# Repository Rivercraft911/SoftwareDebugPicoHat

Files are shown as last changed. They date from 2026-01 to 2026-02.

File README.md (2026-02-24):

# Software Debug Pico Hat

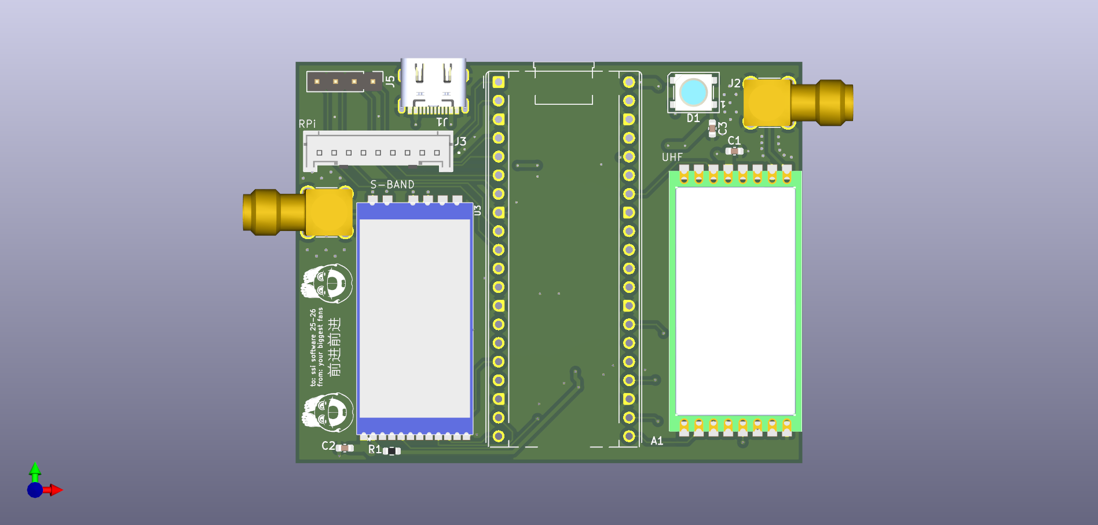
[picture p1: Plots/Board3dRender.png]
Board Render


A simple breakout board for the Raspberry Pi Pico, designed for S-Band and UHF LORA modules. It also includes exposed gpio pins for connection to other boards within the Samwise avionics stack.

[View Schematic PDF](Plots/SoftwareDebugPicoHat.pdf)

## Power

//type this up later frfr

## Pinout

This board connects to a Raspberry Pi Pico and provides the following pinouts:

### Raspberry Pi Communication
| Pin | Function | Pico Pin |
|-----|---|---|
| 0 | RPI_TX | GP0 |
| 1 | RPI_RX | GP1 |
| 2 | RPI_ENABLE | GP2 |
| 3 | RPI_RESET | GP3 |

### ACDS Communication
| Pin | Function | Pico Pin |
|-----|---|---|
| 4 | ACDS_TX | GP4 |
| 5 | ACDS_RX | GP5 |

### S-Band Module (LORA1280F27-TCXO)
| Pin | Function | Pico Pin |
|-----|---|---|
| 8 | SBAND_RST | GP8 |
| 9 | SBAND_BUSY | GP9 |
| 10  | SBAND_TXEN | GP10 |
| 11  | SBAND_RXEN | GP11 |
| 12  | SBAND_MISO | GP12 |
| 13  | SBAND_CS | GP13 |
| 14  | SBAND_SCK | GP14 |
| 15  | SBAND_MOSI | GP15 |
| 20  | SBAND_D1 | GP20 |

### UHF LORA Module (RFM98PW)
| Pin | Function | Pico Pin |
|-----|---|---|
| 16  | UHF_MISO | GP16 |
| 17  | UHF_CS | GP17 |
| 18  | UHF_SCK | GP18 |
| 19  | UHF_MOSI | GP19 |
| 20  | UHF_RST | GP21 |
| 28  | UHF_D0 | GP28 |

### Miscellaneous
| Pin | Function | Pico Pin |
|-----|---|---|
| 26  | NEOPIXEL | GP26 |
| 6 | MISC | GP6 |
| 7 | MISC | GP7 |

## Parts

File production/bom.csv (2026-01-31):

Designator | Footprint | Quantity | Value | LCSC Part #
A1 | RaspberryPi_Pico_Common_THT | 1 | RaspberryPi_Pico
C1, C2, C3 | 0603 | 3 | 0.1uF
D1 | LED_WS2812B_PLCC4_5.0x5.0mm_P3.2mm | 1 | 1655
J1 | Molex_35362-0950 | 1 | 35362-0950
J2, J4 | SMA_Amphenol_901-144_horizontal | 2 | Conn_Coaxial
J3 | USB_C_Receptacle_XKB_U262-161N-4BVC11 | 1 | USB_C_Receptacle_USB2.0_14P
J5 | PinHeader_1x04_P2.54mm_Vertical | 1 | Conn_01x04_Pin
R1 | 0603 | 1 | 10k
U1 | RFM98PW | 1 | RFM98PW
U3 | LORA128XF27 | 1 | LORA1280F27-TCXO

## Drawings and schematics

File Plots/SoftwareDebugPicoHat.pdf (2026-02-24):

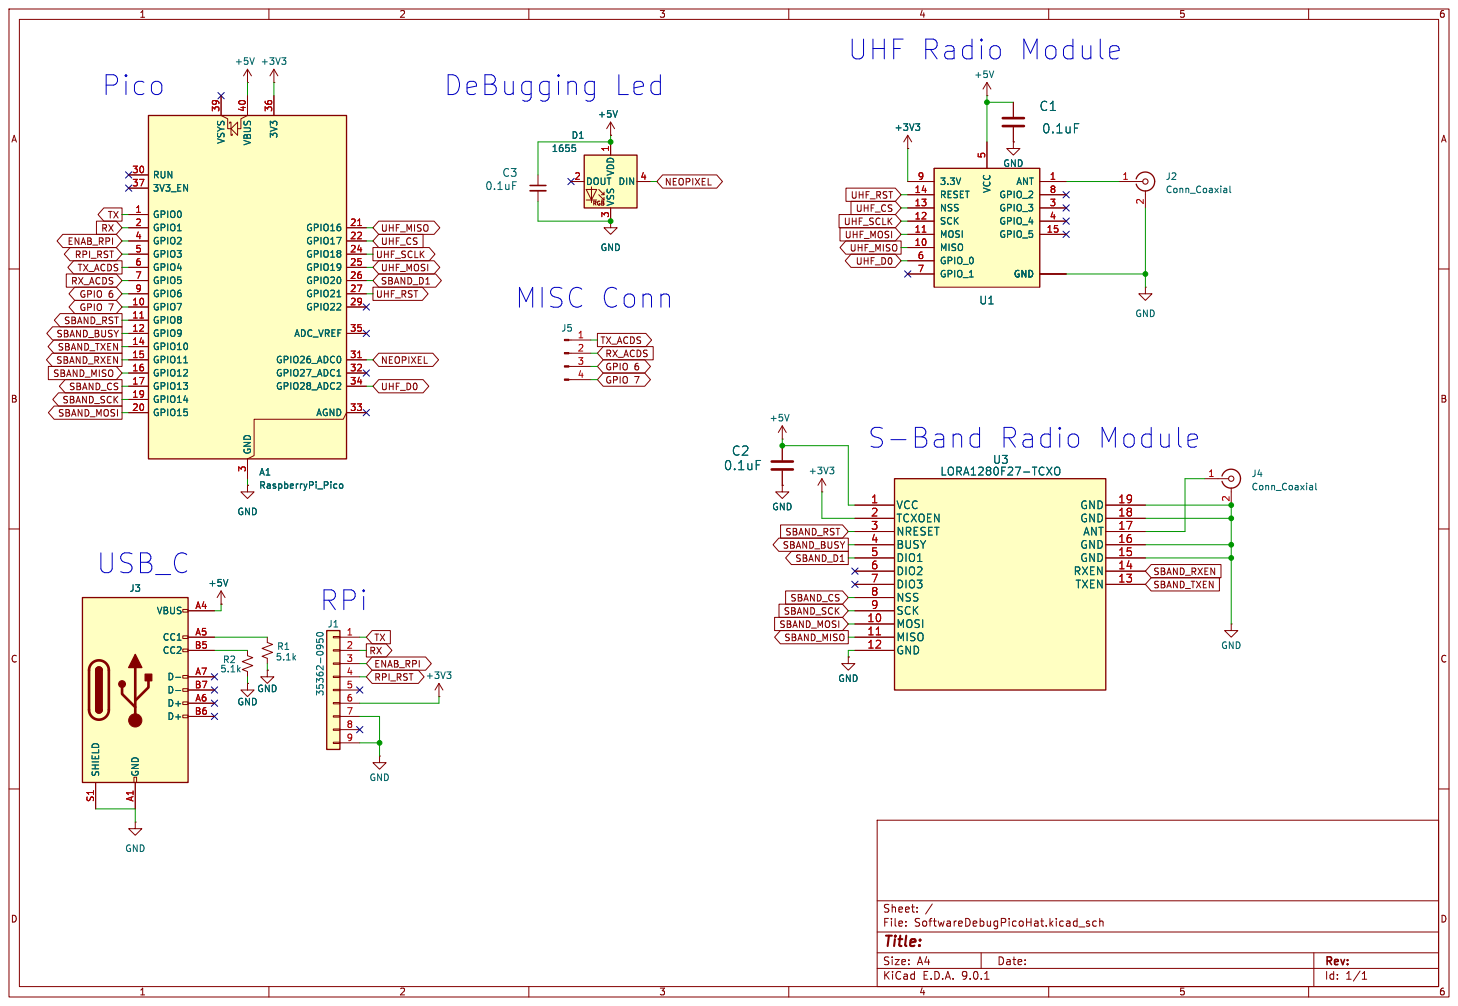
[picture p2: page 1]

Id: 1/1 Title: File: SoftwareDebugPicoHat.kicad_sch Sheet: / GND

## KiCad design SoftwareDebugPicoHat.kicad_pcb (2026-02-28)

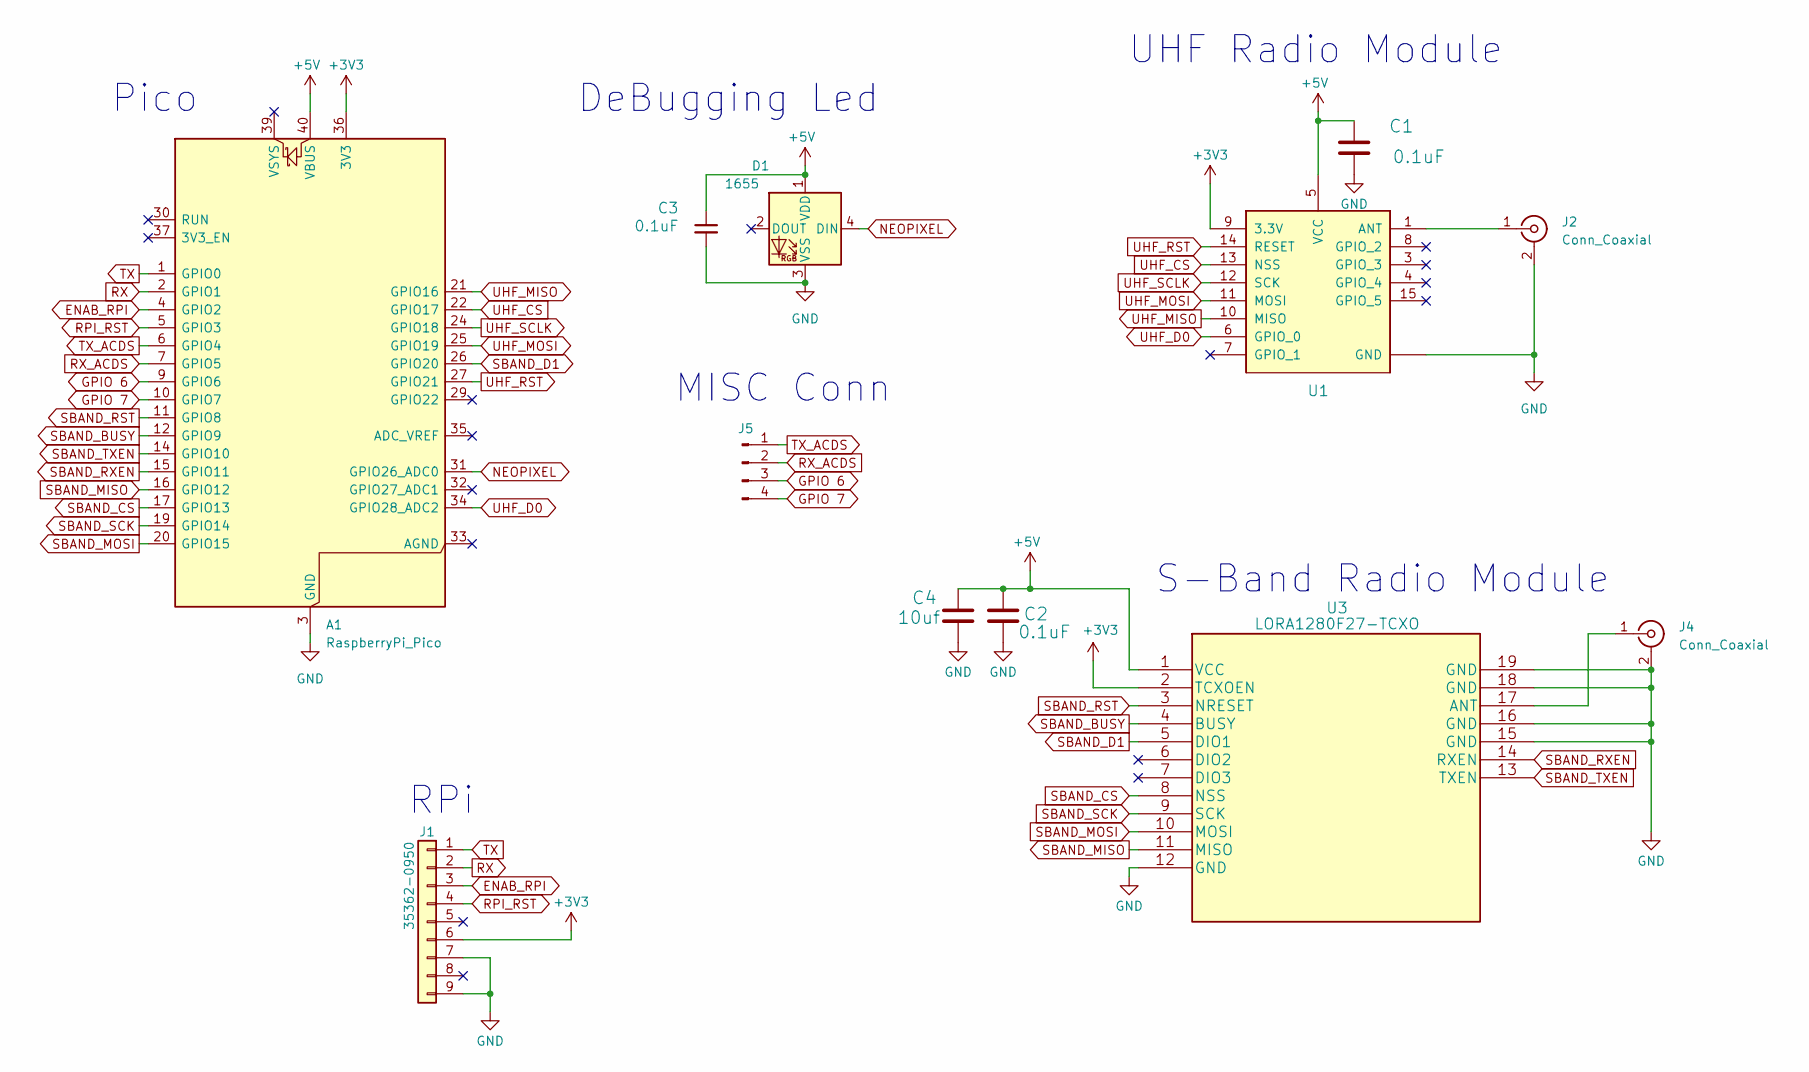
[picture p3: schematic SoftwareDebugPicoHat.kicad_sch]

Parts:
A1: RaspberryPi_Pico; RaspberryPi_Pico_Common_THT
C1, C2, C3: 0.1uF; C_0603_1608Metric
C4: 10uf; C_0603_1608Metric
D1: 1655; LED_WS2812B_PLCC4_5.0x5.0mm_P3.2mm; Manufacturer_Part_Number SK6812
J1: 35362-0950; Molex_35362-0950
J2, J4: Conn_Coaxial; SMA_Amphenol_901-144_horizontal
J5: Conn_01x04_Pin; PinHeader_1x04_P2.54mm_Vertical
U1: RFM98PW
U3: LORA1280F27-TCXO; LORA128XF27

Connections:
+3V3: A1.36 (3V3), J1.6, U1.9 (3.3V), U3.2 (TCXOEN)
+5V: A1.40 (VBUS), C1.1, C2.1, C3.1, C4.1, D1.1 (VDD), U1.5 (VCC), U3.1 (VCC)
ENAB_RPI: A1.4 (GPIO2), J1.3
GND: A1.3 (GND), A1.8 (GND), A1.13 (GND), A1.18 (GND), A1.23 (GND), A1.28 (GND), A1.38 (GND), C1.2, C2.2, C3.2, C4.2, D1.3 (VSS), J1.7, J1.9, J2.2 (Ext), J4.2 (Ext), U1.2 (GND), U1.16 (GND), U1.17 (GND), U3.12 (GND), U3.15 (GND), U3.16 (GND), U3.18 (GND), U3.19 (GND)
GPIO 6: A1.9 (GPIO6), J5.3
GPIO 7: A1.10 (GPIO7), J5.4
NEOPIXEL: A1.31 (GPIO26_ADC0), D1.4 (DIN)
unnamed: J2.1 (In), U1.1 (ANT)
unnamed: J4.1 (In), U3.17 (ANT)
RPI_RST: A1.5 (GPIO3), J1.4
RX: A1.2 (GPIO1), J1.2
RX_ACDS: A1.7 (GPIO5), J5.2
SBAND_BUSY: A1.12 (GPIO9), U3.4 (BUSY)
SBAND_CS: A1.17 (GPIO13), U3.8 (NSS)
SBAND_D1: A1.26 (GPIO20), U3.5 (DIO1)
SBAND_MISO: A1.16 (GPIO12), U3.11 (MISO)
SBAND_MOSI: A1.20 (GPIO15), U3.10 (MOSI)
SBAND_RST: A1.11 (GPIO8), U3.3 (NRESET)
SBAND_RXEN: A1.15 (GPIO11), U3.14 (RXEN)
SBAND_SCK: A1.19 (GPIO14), U3.9 (SCK)
SBAND_TXEN: A1.14 (GPIO10), U3.13 (TXEN)
TX: A1.1 (GPIO0), J1.1
TX_ACDS: A1.6 (GPIO4), J5.1
UHF_CS: A1.22 (GPIO17), U1.13 (NSS)
UHF_D0: A1.34 (GPIO28_ADC2), U1.6 (GPIO_0)
UHF_MISO: A1.21 (GPIO16), U1.10 (MISO)
UHF_MOSI: A1.25 (GPIO19), U1.11 (MOSI)
UHF_RST: A1.27 (GPIO21), U1.14 (RESET)
UHF_SCLK: A1.24 (GPIO18), U1.12 (SCK)

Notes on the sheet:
Pico
MISC Conn
RPi
UHF Radio Module
S-Band Radio Module
DeBugging Led

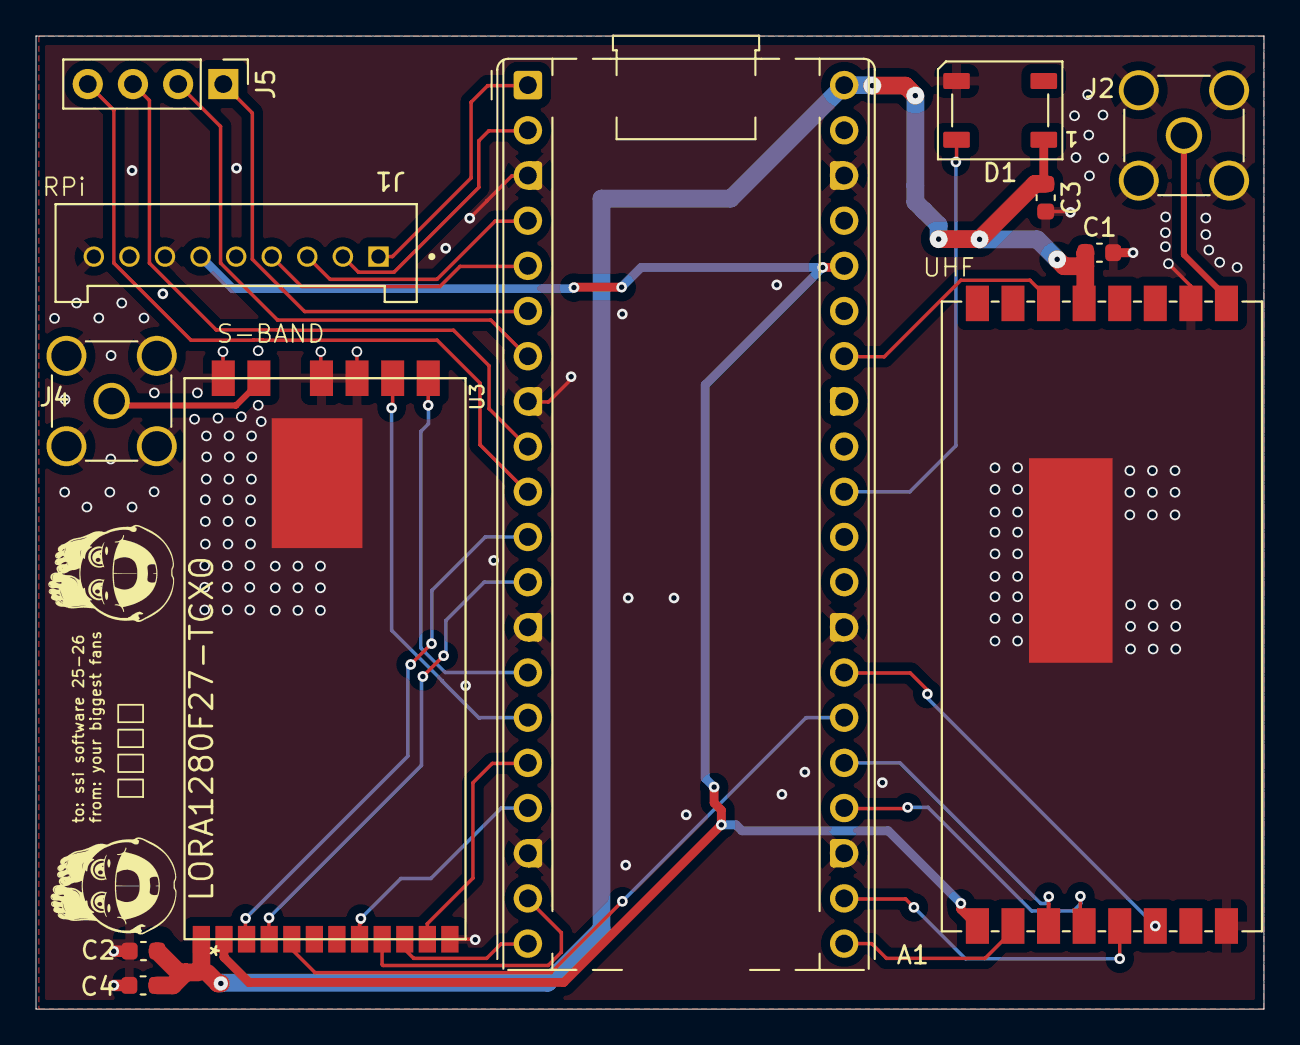
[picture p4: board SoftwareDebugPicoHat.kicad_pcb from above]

Board: 4 copper layers, 69.0 x 54.7 mm, 12 parts (0 on the bottom side), 29 nets.

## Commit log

2026-01-31 Updated to throughhole pico
    [SoftwareDebugPicoHat.kicad_pcb, SoftwareDebugPicoHat.kicad_sch]
2026-01-31 Removed Prod File
    [bom.csv, designators.csv, positions.csv]
2026-01-31 RELEASE: 1 ) Updated some component locations for better placement
    [SoftwareDebugPicoHat.kicad_pcb, bom.csv, designators.csv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]
2026-01-31 Closed FIle
    [SoftwareDebugPicoHat.kicad_pcb]
2026-02-03 Added READ.me and fixed org sys
    [SoftwareDebugPicoHat.kicad_pcb, SoftwareDebugPicoHat.kicad_sch, bom.csv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]
2026-02-03 Updated READ.me to include the power stipulation
2026-02-16 Update UHF_RST pin mapping from GP20 to GP21
2026-02-24 Update power section in README
    Clarified power requirements for S-Band and UHF LoRa modules.
2026-02-24 Solving Samwise
    [SoftwareDebugPicoHat.kicad_sch]
2026-02-27 Removed UBC and TCXO-EN Pullup resistor
    [SoftwareDebugPicoHat.kicad_pcb, SoftwareDebugPicoHat.kicad_sch]
2026-02-28 FIxed Caps
    [SoftwareDebugPicoHat.kicad_pcb, SoftwareDebugPicoHat.kicad_sch]
